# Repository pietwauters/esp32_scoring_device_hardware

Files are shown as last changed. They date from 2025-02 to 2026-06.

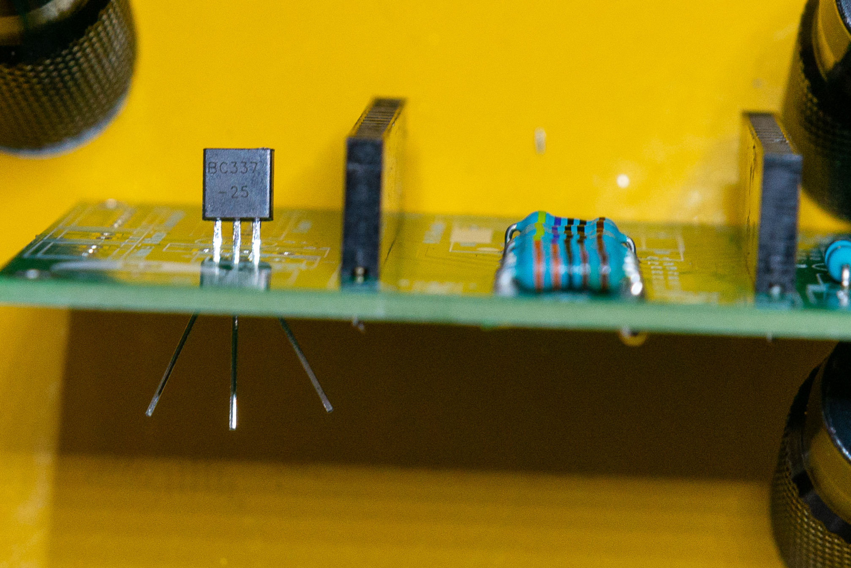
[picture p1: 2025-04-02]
images/pcb/rev1.2x/img111.jpg

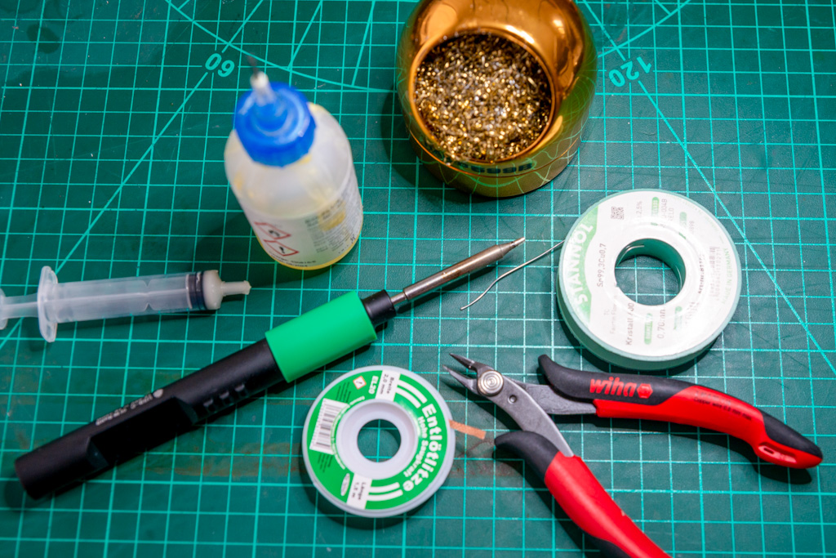
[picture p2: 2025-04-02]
images/pcb/rev1.2x/img100.jpg

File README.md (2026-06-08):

# esp32_scoring_device_hardware
Hardware files for the [low cost scoring device based on a esp32 development board](https://github.com/pietwauters/esp32-scoring-device/wiki). The Wiki is slightly outdated as we now use an update for the PCB. It is just there for historical reasons. There is a [walkthrough on how to assemble the scoring device](https://github.com/pietwauters/esp32_scoring_device_hardware/blob/main/Walkthrough%20to%20buildOpenPiste%20%20Fencing%20Scoring%20Machine.docx).
The current firmware is found on [latest version of the firmware](https://github.com/pietwauters/esp32scoringdeviceMqtt)

You can use the same hardware to make an accurate [wire / weapon tester](https://github.com/pietwauters/WeaponWireTester). (You only have to replace the 470 Ohm resitors by 47 Ohm resistor) See: https://github.com/pietwauters/WeaponWireTester

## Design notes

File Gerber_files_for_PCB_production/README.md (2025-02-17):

> [!IMPORTANT]
> These files are generated from KiCad with the settings required by JLCPCB
> If you need different settings, let me know.

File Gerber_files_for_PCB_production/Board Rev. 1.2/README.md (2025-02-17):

You basically just need to upload the .zip file to the PCB manufacturer

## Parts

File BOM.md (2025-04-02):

# BOM - Bill of materials  PCB rev. 1.2b

> [!NOTE]
> All items marked with * are optional. JST or header connectors can be substituted by soldering the wires directly to the board or ESP.

> [!TIP]
> JST- XH 2.54mm are the recommended connector type for the connectors because they are keyed and you can't connect them the wrong way.
> Simple header pins work fine too, but make sure to orient the plug correctly. 
> JSTs can be bought as kit with wire and crimper. 
> Connectors are preferred over soldering directly to the board for serviceability.

## 1) Three weapon scoring device

| Number of pieces | Designator | Description | Value | Size | Remarks |
| --- | --- | --- | --- | --- | --- |
| 1* | | PCB |Rev 1.2b|| alternatively you could build the circuit on a breadboard or perfboard|
| 1 | U1 | ESP32 DevKit V1 |  |  |  be sure to get the **30 pin** version (2 x 15). There are many board flavors out there e.g. V4 is 38 pin |
| 2 |  | 64 LED matrix panel | WS2812B-64 led matrix | 65mm x 65mm | |
| 1* |  | MAX7219 Dot matrix Module 4-in-1 LED Display module | | | |
| 2 | C1,C3 | radial electrolytic capacitor | 470µF - 35V | Ø10mm - 5mm pitch | |
| 2 | C2,C4 | polyester film capacitor | 0,1µF | L7,3 x W2,5mm | |
| 2 | Q1,Q2 | BC337 NPN transistor | 0,8A 45V | TO-92 | | |
| 5 | R1,R2,R3,R4,R5 | metal film resistor | 470Ω 1% | 1/4W | |
| 2 | R6,R7 | metal film resistor | 33Ω 1% | 1/4W | |
| 1 | R8 | metal film resistor | 3,3kΩ 1% | 1/4W | |
| 1 | R9 | metal film resistor | 2,2kΩ 1% | 1/4W | |
| 1 | R10 | metal film resistor | 150Ω 1% | 1/4W | |
| 1* | R11 | metal film resistor | 0Ω bridge | 1/4W | can be substituted by a simple wire bridge |
| 7 |  | female banana jack | | 4mm, panel mount | |
| 1 | R12 | metal film resistor | 10kΩ 1% | 1/4W | |
| 1* | J1 | JST connector | 1 x 7 | 2,54mm pitch | |
| 1* | J2 | JST connector | 1 x 3 | 2,54mm pitch | |
| 1* | J3 | JST connector | 1 x 5 | 2,54mm pitch | |
| 2* | J8,J9 | JST connector | 1 x 2 | 2,54mm pitch | populate as required|
| 2* |  | pin strip, socket (female) | 1 x 15 | 2,54mm pitch | header for the ESP32 board |
| 1* | Q3 | power mosfet| FQP27P06 | TO-220 | reverse voltage protection, strongly recommended if you power externally via J9 |
| 1* | J4 | Right angle 2,54mm socket| | 6-pin | for plug-in connection of a HC-06 BT module |

### Hardware
| Number of pieces | Description | Remarks |
| --- | --- |  --- |
| 4 | M3 x 20 screw | cylinder or round head |
| 4* | hotmelt threaded inserts M3 | short, medium or long will fit, long preferred |
| 18 | M2 x 6-10 screw | shorter for the PCB and buzzer, longer ones for the retainers |
| 18* | hotmelt threaded inserts M2 | short or medium, long will fit for the PCB |

## 2) Weapons / body wire tester

| Number of pieces | Designator | Description | Value | Size | Remarks |
| --- | --- | --- | --- | --- | --- |
| 1* | | PCB |Rev 1.2b|| alternatively you could build the circuit on a breadboard or perfboard|
| 1 | U1 | ESP32 DevKit V1 | | |  be sure to get the **30 pin** version (2 x 15). There are many board flavors out there e.g. V4 is 38 pin |
| 1 |  | 25 LED matrix panel | WS2812B-25 led matrix | 38mm x 38mm | |
| 2 | C1,C3 | radial electrolytic capacitor | 470µF - 35V | Ø10mm - 5mm pitch | |
| 2 | C2,C4 | polyester film capacitor | 0,1µF | L7,3 x W2,5mm | |
| 5 | R1,R2,R3,R4,R5 | metal film resistor | **47Ω 1%** | 1/4W | These resistors are marked 470Ω* on the silkscreen |
| 2 | R6,R7 | metal film resistor | 33Ω 1% | 1/4W | |
| 7 |  | female banana jack | | 4mm, panel mount | |
| 1* | J1 | JST connector | 1 x 7 | 2,54mm pitch | |
| 1* | J2 | JST connector | 1 x 3 | 2,54mm pitch | |

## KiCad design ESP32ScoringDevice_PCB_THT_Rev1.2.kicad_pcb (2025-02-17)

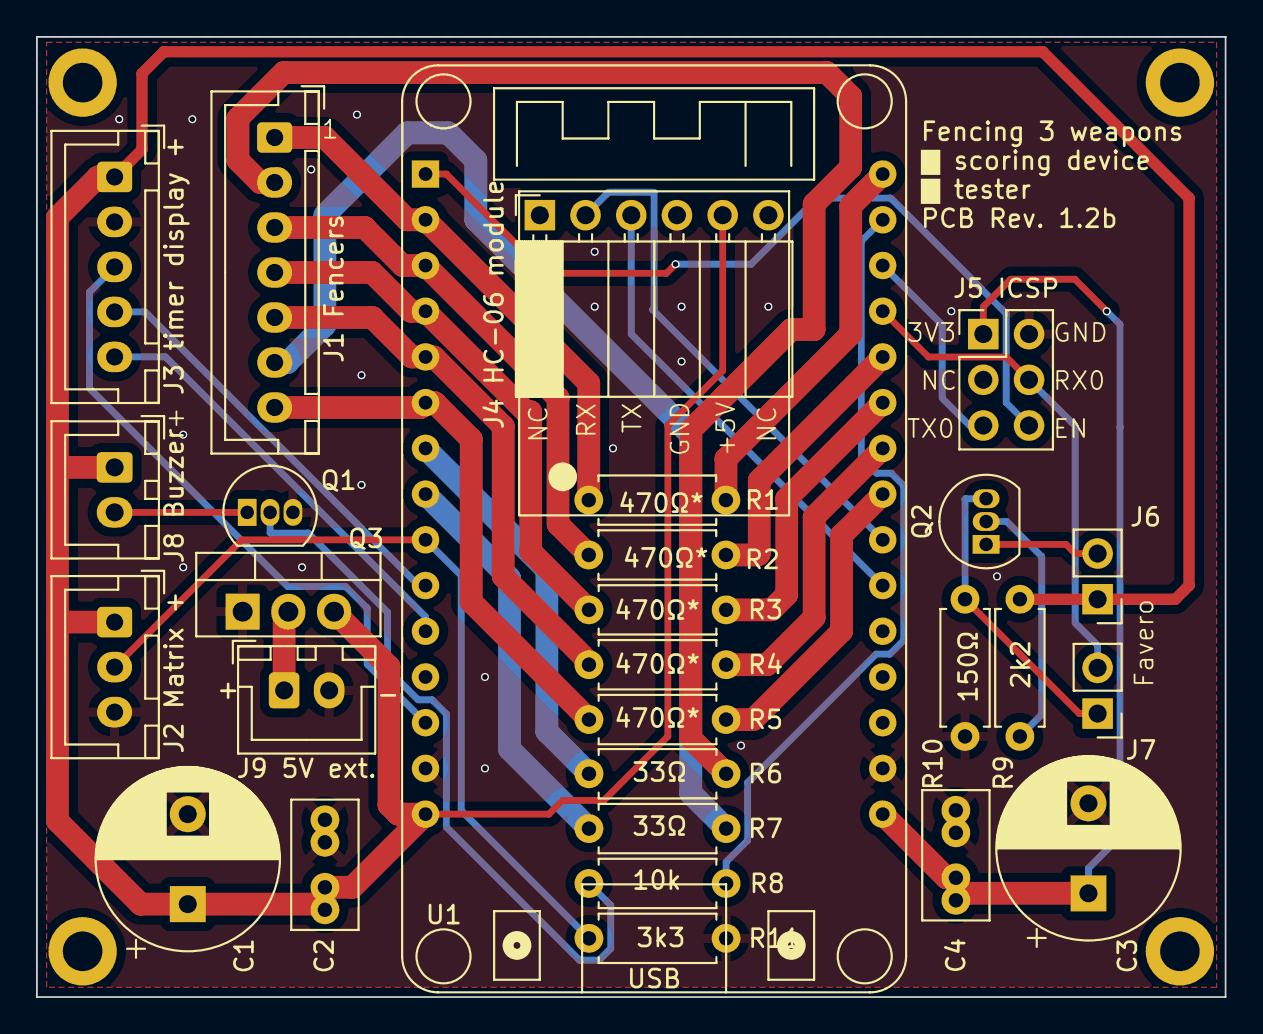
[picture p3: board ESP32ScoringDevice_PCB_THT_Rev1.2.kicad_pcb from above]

Board: 2 copper layers, 66.0 x 53.3 mm, 32 parts (0 on the bottom side), 33 nets.

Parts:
C1, C3: 470µF; CP_Radial_D10.0mm_P5.00mm
C2, C4: 100nF; C_Rect_L7.0mm_W3.5mm_P2.50mm_P5.00mm
H1, H2, H3, H4: MountingHole_2.2mm_M2_DIN965_Pad
J1 Fencers: Fencers; JST_XH_B7B-XH-A_1x07_P2.50mm_Vertical
J2 Matrix +: WS2812B LED Matrix; JST_XH_B3B-XH-A_1x03_P2.50mm_Vertical
J3 timer display +: MAX7219 Timer Display; JST_XH_B5B-XH-A_1x05_P2.50mm_Vertical
J4 HC-06 module: HC-06 BT module; PinSocket_1x06_P2.54mm_Horizontal
J5 ICSP: ICSP; PinHeader_2x03_P2.54mm_Vertical
J6, J7: Conn_01x02; PinHeader_1x02_P2.54mm_Vertical
J8 Buzzer: Buzzer; JST_XH_B2B-XH-A_1x02_P2.50mm_Vertical
J9 5V ext.: 5V ext. Power; JST_XH_B2B-XH-A_1x02_P2.50mm_Vertical
Q1, Q2: BC337; TO-92_Inline
Q3: FQP27P06; TO-220-3_Vertical
R1, R2, R3, R4, R5: 470Ω; R_Axial_DIN0207_L6.3mm_D2.5mm_P7.62mm_Horizontal
R6, R7: 33Ω; R_Axial_DIN0207_L6.3mm_D2.5mm_P7.62mm_Horizontal
R8: 3k3; R_Axial_DIN0207_L6.3mm_D2.5mm_P7.62mm_Horizontal
R9: 2k2; R_Axial_DIN0207_L6.3mm_D2.5mm_P7.62mm_Horizontal
R10: 150Ω; R_Axial_DIN0207_L6.3mm_D2.5mm_P7.62mm_Horizontal
R11: 10k; R_Axial_DIN0207_L6.3mm_D2.5mm_P7.62mm_Horizontal
U1: ESP32_DevKit_V1_DOIT 30pin; esp32_devkit_v1_doit

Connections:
+3.3V: C3.1, C4.1, J5 ICSP.1, U1.16 (3V3)
+5V: C1.1, C2.1, J2 Matrix +.1, J3 timer display +.1, J4 HC-06 module.5, J6.1, J8 Buzzer.1, Q3.3 (S), R9.2, U1.15 (VIN)
GND: C1.2, C2.2, C3.2, C4.2, J2 Matrix +.3, J3 timer display +.2, J4 HC-06 module.4, J5 ICSP.2, J9 5V ext..2, Q1.3 (E), Q3.1 (G), R10.2, R11.2, U1.14 (GND), U1.17 (GND)
unnamed: J1 Fencers.1, R1.2, U1.2 (SENSOR_VP)
unnamed: J1 Fencers.2, R6.2
unnamed: J1 Fencers.3, R2.1, U1.3 (SENSOR_VN)
unnamed: J1 Fencers.4, R3.2, U1.4 (IO34)
unnamed: J1 Fencers.5, R4.2, U1.5 (IO35)
unnamed: J1 Fencers.6, R7.2
unnamed: J1 Fencers.7, R5.2, U1.6 (IO32)
unnamed: J2 Matrix +.2, R11.1, U1.9 (IO26)
unnamed: J3 timer display +.3, U1.13 (IO13)
unnamed: J3 timer display +.4, U1.10 (IO27)
unnamed: J3 timer display +.5, U1.11 (IO14)
unnamed: J4 HC-06 module.2, U1.22 (IO17)
unnamed: J4 HC-06 module.3, U1.21 (IO16)
unnamed: J5 ICSP.4, J7.2, U1.27 (RXD0/IO3)
unnamed: J5 ICSP.5, U1.28 (TXD0/IO1)
unnamed: J5 ICSP.6, U1.1 (EN)
unnamed: J6.2, Q2.1 (C)
unnamed: J7.1, Q2.3 (E), R10.1
unnamed: J8 Buzzer.2, Q1.1 (C)
unnamed: J9 5V ext..1, Q3.2 (D)
unnamed: Q1.2 (B), R8.1
unnamed: Q2.2 (B), R9.1
unnamed: R5.1, U1.23 (IO5)
unnamed: R4.1, U1.24 (IO18)
unnamed: R3.1, U1.25 (IO19)
unnamed: R2.2, U1.26 (IO21)
unnamed: R8.2, U1.29 (IO22)
unnamed: R1.1, U1.30 (IO23)
unnamed: R7.1, U1.8 (IO25)
unnamed: R6.1, U1.7 (IO33)

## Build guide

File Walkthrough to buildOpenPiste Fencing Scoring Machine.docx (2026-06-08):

Walkthrough to build an Arduino Fencing Scoring Machine/Tester.

Check

https://github.com/pietwauters/esp32-scoring-device

https://github.com/pietwauters/esp32_scoring_device_hardware

https://github.com/pietwauters/remotecontrolapp

https://github.com/pietwauters/WeaponWireTester

For mopre info

Part list.

https://github.com/pietwauters/esp32_scoring_device_hardware/blob/main/BOM.md

Note

All items marked with * are optional. JST or header connectors can be substituted by soldering the wires directly to the board or ESP.

Tip

JST- XH 2.54mm are the recommended connector type for the connectors because they are keyed and you can't connect them the wrong way (SEEMS AS IT IS NOT TRUE FOR J2 POWER CONNECTORS). Simple header pins work fine too, but make sure to orient the plug correctly. JSTs can be bought as kit with wire and crimper. Connectors are preferred over soldering directly to the board for serviceability.

Tip

Buy pin strip, socket (female) 1 x 15 2,54mm pitch wide enough to accomodate the ESP32 board

## 3 weapon scoring device

Number of pieces | Designator | Description | Value | Size | Remarks
1* | | PCB | Rev 1.2b | | alternatively you could build the circuit on a breadboard or perfboard
1 | U1 | ESP32 DevKit V1 | | | be sure to get the 30 pin version (2 x 15). There are many board flavors out there e.g. V4 is 38 pin
2 | | 64 LED matrix panel | WS2812B-64 led matrix | 65mm x 65mm
1* | | MAX7219 Dot matrix Module 4-in-1 LED Display module
2 | C1,C3 | radial electrolytic capacitor | 470µF - 35V | Ø10mm - 5mm pitch
2 | C2,C4 | polyester film capacitor | 0,1µF | L7,3 x W2,5mm
2 | Q1,Q2 | BC337 NPN transistor | 0,8A 45V | TO-92
5 | R1,R2,R3,R4,R5 | metal film resistor | 470Ω 1% 47Ω 1% for tester | 1/4W
2 | R6,R7 | metal film resistor | 33Ω 1% 47Ω 1% for tester | 1/4W
1 | R8 | metal film resistor | 3,3kΩ 1% | 1/4W
1 | R9 | metal film resistor | 2,2kΩ 1% | 1/4W
1 | R10 | metal film resistor | 150Ω 1% | 1/4W
1* | R11 | metal film resistor | 0Ω bridge | 1/4W | can be substituted by a simple wire bridge
7 | | female banana jack | | 4mm, panel mount
1 | R12 | metal film resistor | 10kΩ 1% | 1/4W
1* | J1 | JST connector | 1 x 7 | 2,54mm pitch
1* | J2 | JST connector | 1 x 3 | 2,54mm pitch
1* | J3 | JST connector | 1 x 5 | 2,54mm pitch
2* | J8,J9 | JST connector | 1 x 2 | 2,54mm pitch | populate as required
2* | | pin strip, socket (female) | 1 x 15 | 2,54mm pitch | header for the ESP32 board
1* | Q3 | power mosfet | FQP27P06 | TO-220 | reverse voltage protection, strongly recommended if you power externally via J9
1* | J4 | Right angle 2,54mm socket | | 6-pin | for plug-in connection of a HC-06 BT module

## Weapons / body wire tester

Number of pieces | Designator | Description | Value | Size | Remarks
1* | | PCB | Rev 1.2b | | alternatively you could build the circuit on a breadboard or perfboard
1 | U1 | ESP32 DevKit V1 | | | be sure to get the 30 pin version (2 x 15). There are many board flavors out there e.g. V4 is 38 pin
1 | | 25 LED matrix panel | WS2812B-25 led matrix | 38mm x 38mm
2 | C1,C3 | radial electrolytic capacitor | 470µF - 35V | Ø10mm - 5mm pitch
2 | C2,C4 | polyester film capacitor | 0,1µF | L7,3 x W2,5mm
5 | R1,R2,R3,R4,R5 | metal film resistor | 47Ω 1% | 1/4W | These resistors are marked 470Ω* on the silkscreen
2 | R6,R7 | metal film resistor | 33Ω 1% | 1/4W
7 | | female banana jack | | 4mm, panel mount
1* | J1 | JST connector | 1 x 7 | 2,54mm pitch
1* | J2 | JST connector | 1 x 3 | 2,54mm pitch

For the JST connectors, I recommend to buy fully assembled versions like: https://nl.aliexpress.com/item/1005002396070880.html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

You will need different versions: 7 pins, 5 pins, 3 pins, 2 pins.

Screws to fix parts: M3 x25mm to close the box. M2x8mm to fix the pcb M3 x6mm for everything else

https://nl.aliexpress.com/item/32810872544.html

Brass insets 2, 3 and 6 mm (OD 8 mm Lenght 6 mm)

https://es.aliexpress.com/item/1005006472702418.html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

https://es.aliexpress.com/item/1005008666672949.html

USB-C feeding connection

https://nl.aliexpress.com/item/1005007463286632.html

WS2812 go for:

https://es.aliexpress.com/item/1005005697976566.html

ESP32 DevKit V1

https://es.aliexpress.com/item/1005008275465796.html

MAX7219 Dot matrix Module 4-in-1 LED Display module

https://es.aliexpress.com/item/1005005855156717.html

WS2812 para el probador:

https://es.aliexpress.com/item/4001251900516.html

4 mm sockets for the connector

https://www.aliexpress.com/item/1005006499956025.html?spm=a2g0o.order_list.order_list_main.139.6ec518021tWRP7

15 pins socket

https://es.aliexpress.com/item/4001198421663.html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

Zumbadores

https://es.aliexpress.com/item/1005006271216453.html

Print the box using a 3D printer.

Print the enclosure for the device using the files in the directory STL or download from:

Scoring device:

https://www.printables.com/model/1138815-enclosure-for-scoring-device

The front part is a multi-color part: black for the box and transparent for the “windows”.

Add the 4 files together in your slicer to treat them as multiple parts of the same object:

ScoringBoxV3_0.3-TransparentWS2812Left.stl

ScoringBoxV3_0.3-TransparentWS2812Right.stl

ScoringBoxV3_0.3-Transparentleddisplay.stl

ScoringBoxV3_0.6-Front.stl

Testing Box:

YAPP_WireTester_v3.2.stl (There is a new versión for the upper part)

You will need a thread cutter for the banana connctors. I print thread, but it is easier if you cut them with a tool. It is M6, with a fine pitch 0.75. (not standard pitch) https://es.aliexpress.com/item/1005005815200788.html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

Other interesting printables are:

https://www.printables.com/model/864187-body-cord-assembly-help

https://www.printables.com/model/1117413-foil-guard-socket-improvement

https://www.printables.com/model/1145428-foil-tip-assembly-help

You will need a thread cutter for the banana connctors. I print thread, but it is easier if you cut them with a tool. It is M6, with a fine pitch 0.75. (not standard pitch) https://es.aliexpress.com/item/1005005815200788.html

Remote control app: https://drive.google.com/file/d/1Urqx_oneAUGP4X9xaYgV_Lu_l0lxvPS3/view?usp=drive_link

Firmware: https://drive.google.com/file/d/1NzSybVZvEsW4hmOQh3sam8iV9_sMTCQC/view?usp=drive_link

First time programming: https://drive.google.com/file/d/1-c_6lXHVxWl4rX92xM3lpi4dTMm7Uuvw/view?usp=sharing

First time programming tool: https://espressif.github.io/esp-launchpad/

1.- Mount the board as described, with 470 Ohm resistances for R1 to R5 and 33 Ohm for R6 ad R7

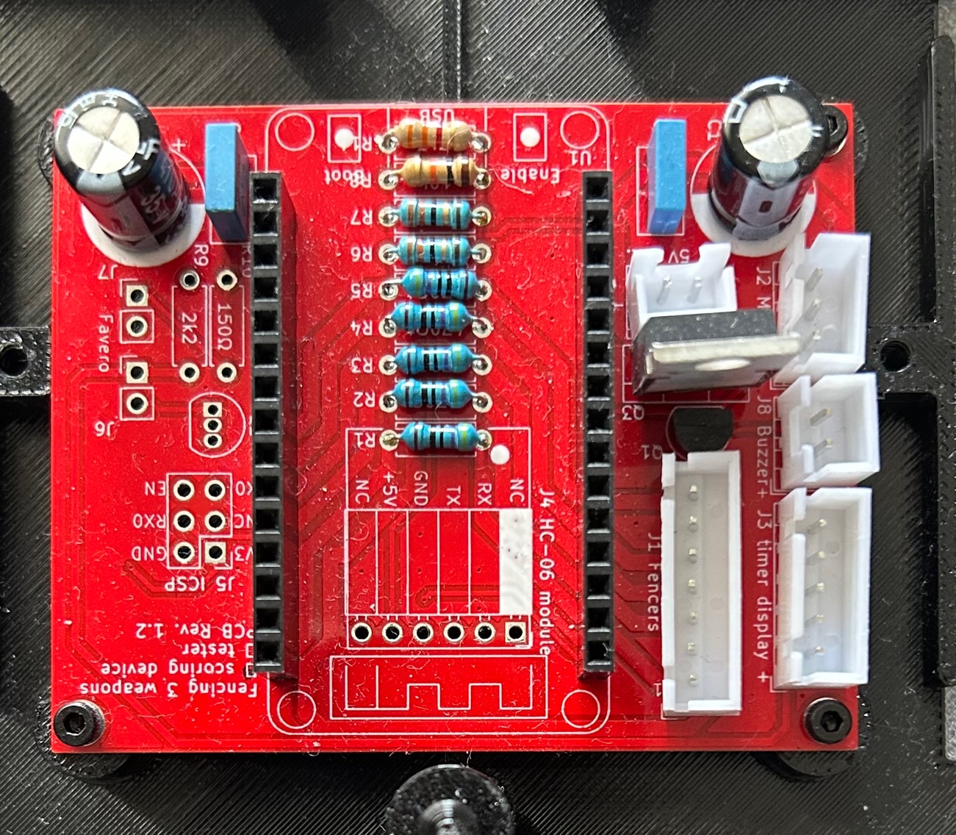
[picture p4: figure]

There is space enough for the board so it is better to use a socket.

Mount it with the USB port facing the buzzer hole, so you can install the buzzer at the end.

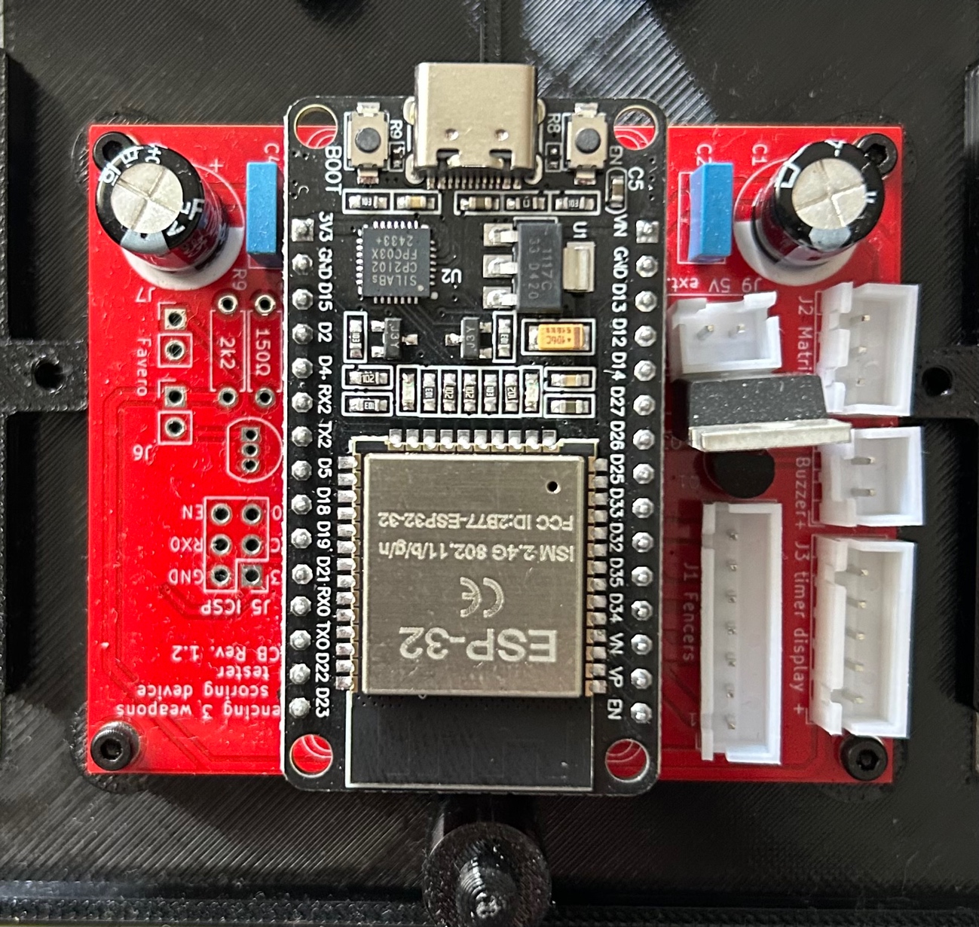
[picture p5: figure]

2- Connect the LED board with the pins facing right

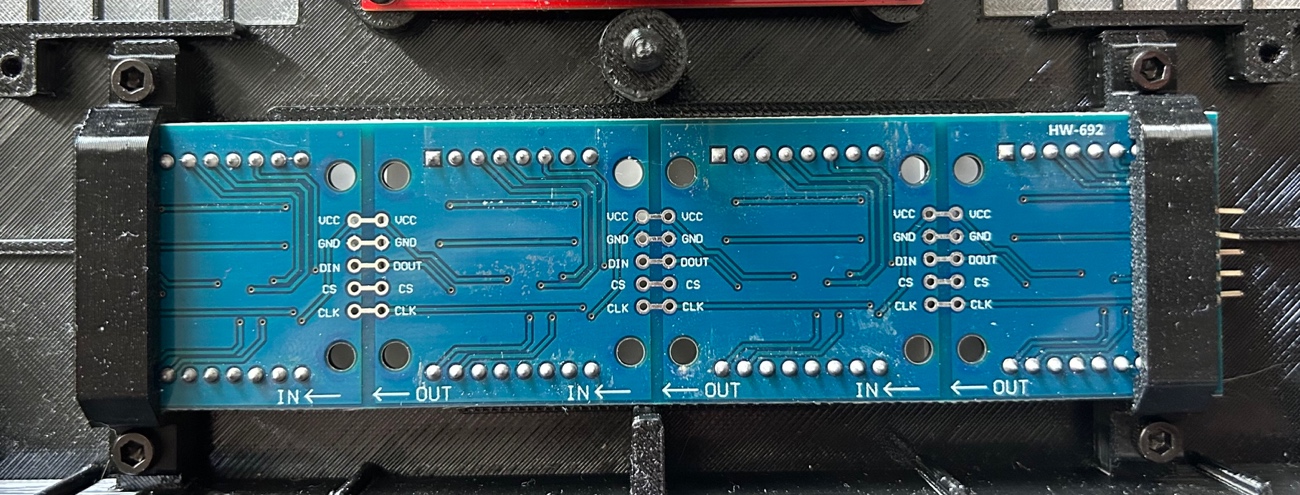
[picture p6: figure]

J5 Connections to the LED BOARD

5 Orange to CLK

4 Yellow to CS

3 White to DIN

2 Red to GND

1 Black to VCC

Pictures of the connections

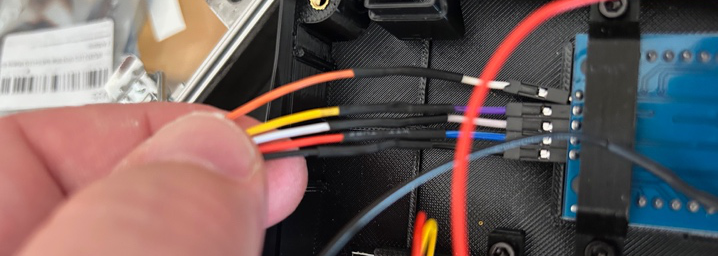
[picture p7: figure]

J3 Connections to the LED Boards

1 Yellow V+

2 Black IN

3 Red V-

Mount both boards upside-down and connect them

V+ top V+

Out to In

V- to V-

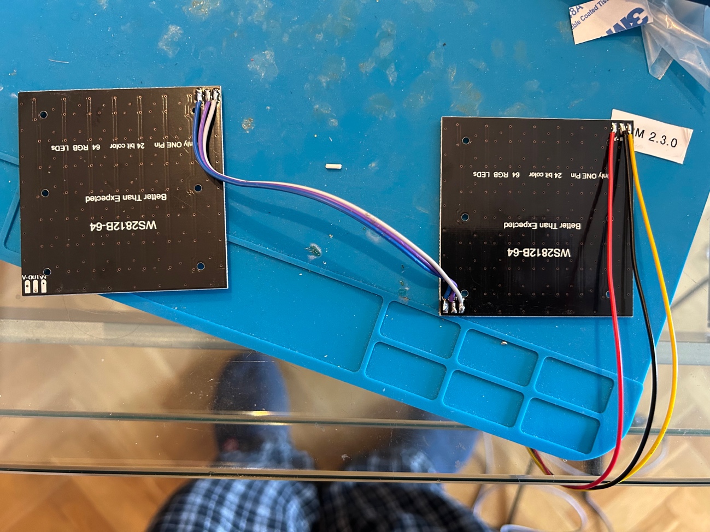
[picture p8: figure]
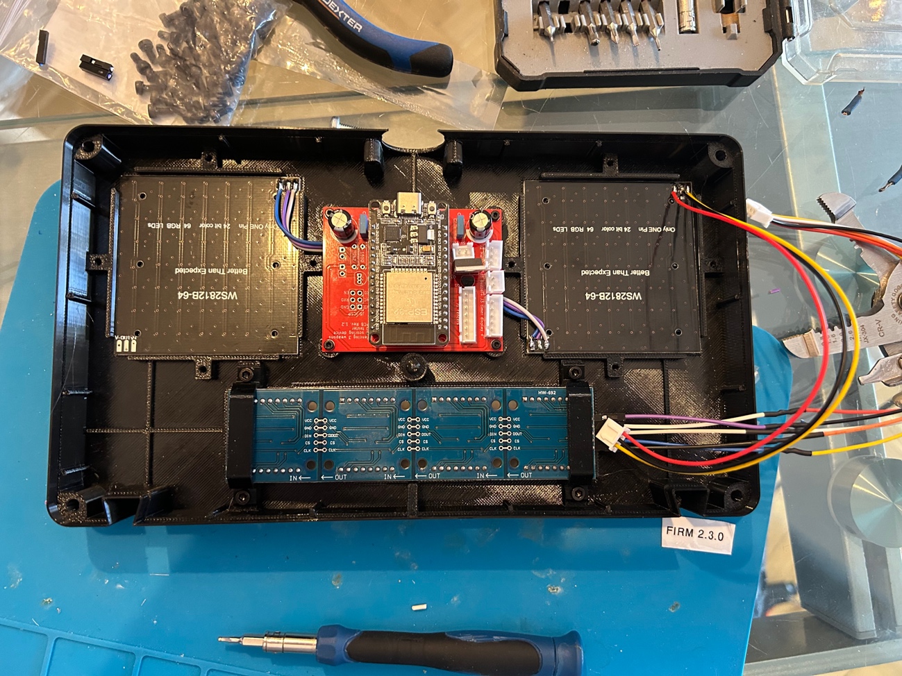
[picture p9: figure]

J7 connectors to the fencers:

From left to right

1 Black

2 Red

3 White

4 Yellow

5 Blue

6 Green

7 Orange

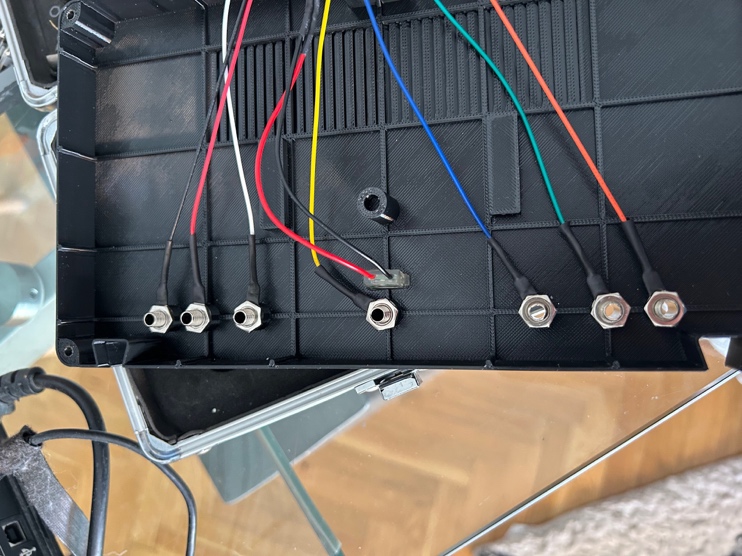
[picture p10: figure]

Install the USB-C connector taking care that the red wire (+) is connected LEFT as seen as from the USB of the ESP Board. Some J2 connectors are reversed, check before installing the socket for power and buzzer.

Select an Smart USB-C connector so you can use any USB-C source and not only 5 V ones.

Connect the board to a computer using the USB port. Get sure that you have the right drivers installed as there are two flavours of ESP ports.

CP2102

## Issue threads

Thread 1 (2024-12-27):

Add project name, board version and author to silkscreen

ClaudeWolter, 2024-12-27:
Hi Piet,

very nice project!
I suggest to add the project name, version and author to the silkscreen ;-)

Kind regards,
Claude

pietwauters, 2024-12-27:
Good point.

Closed 2024-12-29.

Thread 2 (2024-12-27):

Add Gerber files to the repo

ClaudeWolter, 2024-12-27:
Hi Piet,

I ordered some PCBs, if the generated Gerbers work out, I'll upload them here.

Kind regards,
Claude

ClaudeWolter, 2025-02-15:
Added to the repo

Kind regards,
Claude

Closed 2025-02-15.

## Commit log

2023-01-22 Added 10k pull down resistor on the data line of the SW2812b matrices
    [ESP32ScoringDevice.kicad_pcb, ESP32ScoringDevice.kicad_sch]
2024-12-29 Rev 1.1 of the PCB
    Changelog:
    - created ground planes on both sides. R11 is obsolete. Tests have to show if they interfere with Wifi signal. If so, the antenna area has to be spared out more consequently.
    - rerouted the board on 2 sides. No difference in cost if 1 or 2 sided PCB.
    - increased the trace width to 50mil (1,27mm) for less resistance and more consistent resistance values between traces.
    - test boards are ordered, real world tests have to show if this revision is viable. No commit to main branch before validation!
    [ESP32ScoringDevice_PCB_THT_Rev1.1.kicad_pcb]
2025-01-20 Board Rev. 1.2
    [ESP32ScoringDevice_PCB_THT_Rev1.2-B_Cu.gbl, ESP32ScoringDevice_PCB_THT_Rev1.2-B_Mask.gbs, ESP32ScoringDevice_PCB_THT_Rev1.2-B_Silkscreen.gbo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]
2025-01-26 new board rev. 1.2
2025-02-15 Rev 1.2b
    Small tweaks
    [ESP32ScoringDevice_PCB_THT_Rev1.2.kicad_pcb]
2025-02-15 Update to board Rev. 1.2b
2025-02-19 Update BOM rev 1.2b.md
2026-06-08 Enhance README with additional project details
    Updated README to include information about PCB updates, assembly walkthrough, and current firmware location.

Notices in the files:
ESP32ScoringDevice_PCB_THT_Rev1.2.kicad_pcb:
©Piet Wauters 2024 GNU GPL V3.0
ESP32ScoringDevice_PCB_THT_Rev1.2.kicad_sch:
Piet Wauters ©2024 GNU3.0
